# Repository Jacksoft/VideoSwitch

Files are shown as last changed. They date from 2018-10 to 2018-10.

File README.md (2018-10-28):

# VideoSwitch
VideoSwitch sources (PIC + Schematic)
This project is a VideoSwitch for retro devices (that uses SCART/Composite) and is based on a mainboard composed by a PIC microcontroller, a main switch/selector and eight multiplexer, and a daughterboard (to be designed) to add eight more ports (up to two for a total of 24 inputs, not guaranteed until I'll produce a prototype for the right tests).
On the mainboard can be connected an 8x2 LCD character display (or biggher by modifying the firmware), two buttons for the input port selection and an IR receiver (not implemented yet firmware side, need to write the NEC IR library).
The firmware is in MikroBASIC (yes, I'm lazy and this language isn't the best for microcontrollers, I know).
Find out more on http://blog.jacksoftlabs.com/digital-video-switch-for-retro-devices/

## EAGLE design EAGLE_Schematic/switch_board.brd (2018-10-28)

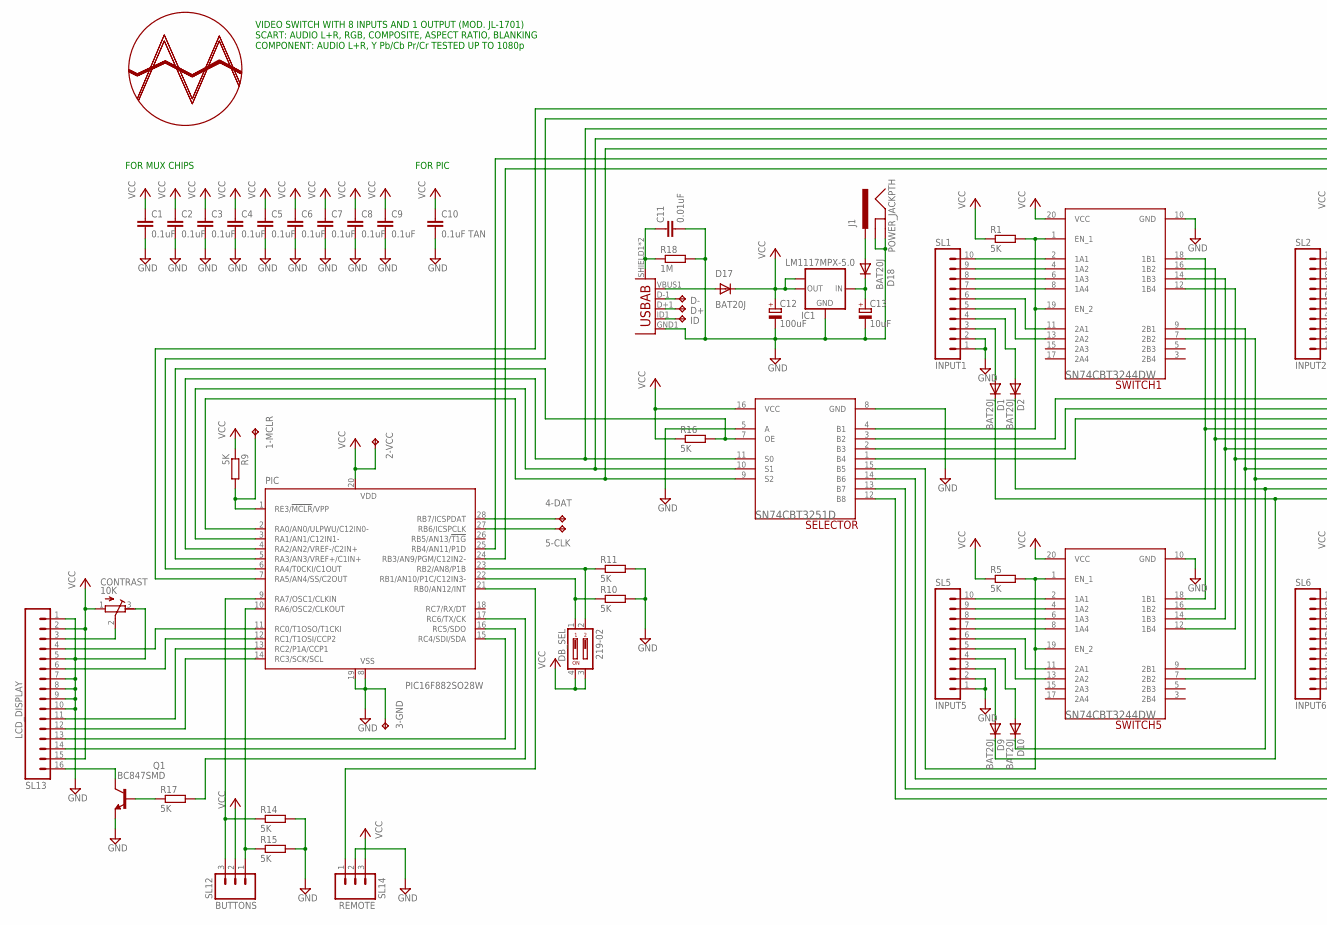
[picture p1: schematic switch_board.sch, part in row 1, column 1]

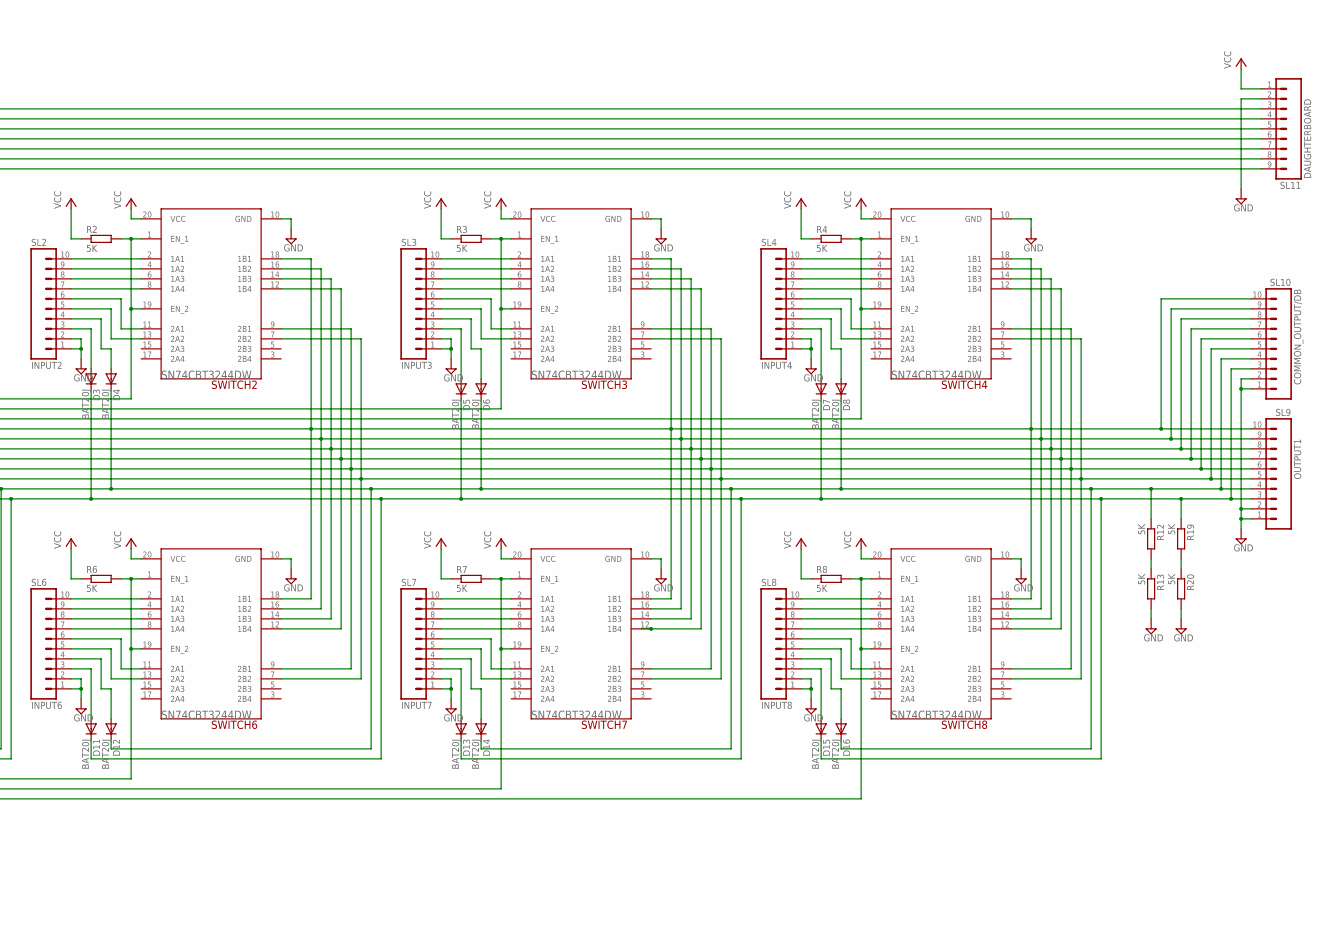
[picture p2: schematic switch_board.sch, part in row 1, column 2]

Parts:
1-MCLR, 2-VCC, 3-GND, 4-DAT, 5-CLK: TPB1,27; B1,27
C1, C2, C3, C4, C5, C6, C7, C8, C9: 0.1uF; C0603
C10: 0.1uF TAN; C3216
C11: 0.01uF; C0603
C12: 100uF; 153CLV-0405
C13: 10uF; 153CLV-0405
CONTRAST: 10K; RTRIM3304W
D1, D2, D3, D4, D5, D6, D7, D8, D9, D10, D11, D12, D13, D14, D15, D16, D17, D18: BAT20J; SOD323-W
D+: TPTP06R; TP06R
D-: TPTP06R; TP06R
DB_SEL: 219-02; CTS-219-02
IC1: LM1117MPX-5.0; SOT223
ID: TPTP06R; TP06R
J1: POWER_JACKPTH; POWER_JACK_PTH
PIC: PIC16F882SO28W; 16F882
Q1: BC847SMD; SOT23
R1, R2, R3, R4, R5, R6, R7, R8, R9, R10, R11, R12, R13, R14, R15, R16, R17, R19, R20: 5K; R0603
R18: 1M; R0603
SELECTOR: SN74CBT3251D; SOIC127P1032X265-16N
SL1: INPUT1; 10P
SL2: INPUT2; 10P
SL3: INPUT3; 10P
SL4: INPUT4; 10P
SL5: INPUT5; 10P
SL6: INPUT6; 10P
SL7: INPUT7; 10P
SL8: INPUT8; 10P
SL9: OUTPUT1; 10P
SL10: COMMON_OUTPUT/DB; 10P
SL11: DAUGHTERBOARD; 09P
SL12: BUTTONS; 03P
SL13: LCD_DISPLAY; 16P
SL14: REMOTE; 03P
SWITCH1, SWITCH2, SWITCH3, SWITCH4, SWITCH5, SWITCH6, SWITCH7, SWITCH8: SN74CBT3244DW; SOIC127P1032X265-20N
U$1: JACKSOFTLABS-LOGOLONGTEXT; LOGO-LONGTEXT
USB: USB_POWER; USB-MICRO-SMD

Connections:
GND: 3-GND.TP, C1.2, C2.2, C3.2, C4.2, C5.2, C6.2, C7.2, C8.2, C9.2, C10.2, C11.2, C12.-, C13.-, CONTRAST.3 (E), IC1.1 (GND), J1.GND, J1.GNDBREAK, PIC.8 (VSS), PIC.19 (VSS), Q1.2 (E), R10.2, R11.2, R13.2, R14.2, R15.2, R18.2, R20.2, SELECTOR.5 (A), SELECTOR.8 (GND), SL1.1, SL1.2, SL2.1, SL2.2, SL3.1, SL3.2, SL4.1, SL4.2, SL5.1, SL5.2, SL6.1, SL6.2, SL7.1, SL7.2, SL8.1, SL8.2, SL9.1, SL9.2, SL10.1, SL10.2, SL11.2, SL13.1, SL13.5, SL13.7, SL13.8, SL13.9, SL13.10, SL14.2, SWITCH1.10 (GND), SWITCH2.10 (GND), SWITCH3.10 (GND), SWITCH4.10 (GND), SWITCH5.10 (GND), SWITCH6.10 (GND), SWITCH7.10 (GND), SWITCH8.10 (GND), USB.GND1 (GND)
unnamed: SL1.10, SWITCH1.2 (1A1)
unnamed: SL1.9, SWITCH1.4 (1A2)
unnamed: SL1.8, SWITCH1.6 (1A3)
unnamed: SL1.7, SWITCH1.8 (1A4)
unnamed: SL1.6, SWITCH1.11 (2A1)
unnamed: SL1.5, SWITCH1.13 (2A2)
unnamed: D2.A, SL1.4
unnamed: D1.A, SL1.3
unnamed: R1.2, SELECTOR.4 (B1), SWITCH1.1 (EN_1), SWITCH1.19 (EN_2)
unnamed: SL2.10, SWITCH2.2 (1A1)
unnamed: SL2.9, SWITCH2.4 (1A2)
unnamed: SL2.8, SWITCH2.6 (1A3)
unnamed: SL2.7, SWITCH2.8 (1A4)
unnamed: SL2.6, SWITCH2.11 (2A1)
unnamed: SL2.5, SWITCH2.13 (2A2)
unnamed: D4.A, SL2.4
unnamed: D3.A, SL2.3
unnamed: R2.2, SELECTOR.3 (B2), SWITCH2.1 (EN_1), SWITCH2.19 (EN_2)
unnamed: SL3.10, SWITCH3.2 (1A1)
unnamed: SL3.9, SWITCH3.4 (1A2)
unnamed: SL3.8, SWITCH3.6 (1A3)
unnamed: SL3.7, SWITCH3.8 (1A4)
unnamed: SL3.6, SWITCH3.11 (2A1)
unnamed: SL3.5, SWITCH3.13 (2A2)
unnamed: D6.A, SL3.4
unnamed: D5.A, SL3.3
unnamed: R3.2, SELECTOR.2 (B3), SWITCH3.1 (EN_1), SWITCH3.19 (EN_2)
unnamed: SL4.10, SWITCH4.2 (1A1)
unnamed: SL4.9, SWITCH4.4 (1A2)
unnamed: SL4.8, SWITCH4.6 (1A3)
unnamed: SL4.7, SWITCH4.8 (1A4)
unnamed: SL4.6, SWITCH4.11 (2A1)
unnamed: SL4.5, SWITCH4.13 (2A2)
unnamed: D8.A, SL4.4
unnamed: D7.A, SL4.3
unnamed: R4.2, SELECTOR.1 (B4), SWITCH4.1 (EN_1), SWITCH4.19 (EN_2)
unnamed: SL9.10, SL10.10, SWITCH1.18 (1B1), SWITCH2.18 (1B1), SWITCH3.18 (1B1), SWITCH4.18 (1B1), SWITCH5.18 (1B1), SWITCH6.18 (1B1), SWITCH7.18 (1B1), SWITCH8.18 (1B1)
unnamed: SL9.9, SL10.9, SWITCH1.16 (1B2), SWITCH2.16 (1B2), SWITCH3.16 (1B2), SWITCH4.16 (1B2), SWITCH5.16 (1B2), SWITCH6.16 (1B2), SWITCH7.16 (1B2), SWITCH8.16 (1B2)
unnamed: PIC.11 (RC0/T1OSO/T1CKI), SL13.4
unnamed: PIC.12 (RC1/T1OSI/CCP2), SL13.6
unnamed: PIC.13 (RC2/P1A/CCP1), SL13.11
unnamed: DB_SEL.1, PIC.22 (RB1/AN10/P1C/C12IN3-), R10.1
unnamed: PIC.14 (RC3/SCK/SCL), SL13.12
unnamed: CONTRAST.2 (S), SL13.3
unnamed: SL5.10, SWITCH5.2 (1A1)
unnamed: SL5.9, SWITCH5.4 (1A2)
unnamed: SL5.8, SWITCH5.6 (1A3)
unnamed: SL5.7, SWITCH5.8 (1A4)
unnamed: SL5.6, SWITCH5.11 (2A1)
unnamed: SL5.5, SWITCH5.13 (2A2)
unnamed: D10.A, SL5.4
unnamed: D9.A, SL5.3
unnamed: R5.2, SELECTOR.15 (B5), SWITCH5.1 (EN_1), SWITCH5.19 (EN_2)
unnamed: SL6.10, SWITCH6.2 (1A1)
unnamed: SL6.9, SWITCH6.4 (1A2)
unnamed: SL6.8, SWITCH6.6 (1A3)
unnamed: SL6.7, SWITCH6.8 (1A4)
unnamed: SL6.6, SWITCH6.11 (2A1)
unnamed: SL6.5, SWITCH6.13 (2A2)
unnamed: D12.A, SL6.4
unnamed: D11.A, SL6.3
unnamed: R6.2, SELECTOR.14 (B6), SWITCH6.1 (EN_1), SWITCH6.19 (EN_2)
unnamed: SL7.10, SWITCH7.2 (1A1)
unnamed: SL7.9, SWITCH7.4 (1A2)
unnamed: SL7.8, SWITCH7.6 (1A3)
unnamed: SL7.7, SWITCH7.8 (1A4)
unnamed: SL7.6, SWITCH7.11 (2A1)
unnamed: SL7.5, SWITCH7.13 (2A2)
unnamed: D14.A, SL7.4
unnamed: D13.A, SL7.3
unnamed: R7.2, SELECTOR.13 (B7), SWITCH7.1 (EN_1), SWITCH7.19 (EN_2)
unnamed: SL8.10, SWITCH8.2 (1A1)
unnamed: SL8.9, SWITCH8.4 (1A2)
unnamed: SL8.8, SWITCH8.6 (1A3)
unnamed: SL8.7, SWITCH8.8 (1A4)
unnamed: SL8.6, SWITCH8.11 (2A1)
unnamed: SL8.5, SWITCH8.13 (2A2)
unnamed: D16.A, SL8.4
unnamed: D15.A, SL8.3
unnamed: R8.2, SELECTOR.12 (B8), SWITCH8.1 (EN_1), SWITCH8.19 (EN_2)
unnamed: DB_SEL.2, PIC.23 (RB2/AN8/P1B), R11.1
unnamed: 1-MCLR.TP, PIC.1 (RE3/!MCLR!/VPP), R9.2
unnamed: PIC.5 (RA3/AN3/VREF+/C1IN+), R16.2, SELECTOR.7 (OE)
unnamed: C11.1, R18.1, USB.SHIELD1 (SHIELD), USB.SHIELD2 (SHIELD)
unnamed: PIC.4 (RA2/AN2/VREF-/C2IN+), SELECTOR.11 (S0), SL11.5
unnamed: PIC.3 (RA1/AN1/C12IN1-), SELECTOR.10 (S1), SL11.6
unnamed: PIC.2 (RA0/AN0/ULPWU/C12IN0-), SELECTOR.9 (S2), SL11.7
unnamed: PIC.6 (RA4/T0CKI/C1OUT), SL11.4
unnamed: 4-DAT.TP, PIC.28 (RB7/ICSPDAT)
unnamed: 5-CLK.TP, PIC.27 (RB6/ICSPCLK)
unnamed: PIC.7 (RA5/AN4/SS/C2OUT), SL11.3
unnamed: Q1.3 (C), SL13.16
unnamed: Q1.1 (B), R17.1
unnamed: D17.A, USB.VBUS1 (VBUS)
unnamed: PIC.21 (RB0/AN12/INT), SL14.1
unnamed: PIC.15 (RC4/SDI/SDA), SL13.13
unnamed: PIC.16 (RC5/SDO), SL13.14
unnamed: PIC.17 (RC6/TX/CK), R17.2
unnamed: C13.+, D18.C, IC1.3 (IN)
unnamed: PIC.10 (RA6/OSC2/CLKOUT), R15.1, SL12.1
unnamed: PIC.9 (RA7/OSC1/CLKIN), R14.1, SL12.3
unnamed: D1.C, D3.C, D5.C, D7.C, D9.C, D11.C, D13.C, D15.C, R19.1, SL9.3, SL10.3
unnamed: D2.C, D4.C, D6.C, D8.C, D10.C, D12.C, D14.C, D16.C, R12.1, SL9.4, SL10.4
unnamed: SL9.5, SL10.5, SWITCH1.7 (2B2), SWITCH2.7 (2B2), SWITCH3.7 (2B2), SWITCH4.7 (2B2), SWITCH5.7 (2B2), SWITCH6.7 (2B2), SWITCH7.7 (2B2), SWITCH8.7 (2B2)
unnamed: SL9.6, SL10.6, SWITCH1.9 (2B1), SWITCH2.9 (2B1), SWITCH3.9 (2B1), SWITCH4.9 (2B1), SWITCH5.9 (2B1), SWITCH6.9 (2B1), SWITCH7.9 (2B1), SWITCH8.9 (2B1)
unnamed: SL9.7, SL10.7, SWITCH1.12 (1B4), SWITCH2.12 (1B4), SWITCH3.12 (1B4), SWITCH4.12 (1B4), SWITCH5.12 (1B4), SWITCH6.12 (1B4), SWITCH7.12 (1B4), SWITCH8.12 (1B4)
unnamed: SL9.8, SL10.8, SWITCH1.14 (1B3), SWITCH2.14 (1B3), SWITCH3.14 (1B3), SWITCH4.14 (1B3), SWITCH5.14 (1B3), SWITCH6.14 (1B3), SWITCH7.14 (1B3), SWITCH8.14 (1B3)
unnamed: D18.A, J1.PWR
unnamed: D-.TP, USB.D-1 (D-)
unnamed: D+.TP, USB.D+1 (D+)
unnamed: ID.TP, USB.ID1 (USBID)
unnamed: R12.2, R13.1
unnamed: R19.2, R20.1
unnamed: PIC.25 (RB4/AN11/P1D), SL11.8
unnamed: PIC.24 (RB3/AN9/PGM/C12IN2-), SL11.9
VCC: 2-VCC.TP, C1.1, C2.1, C3.1, C4.1, C5.1, C6.1, C7.1, C8.1, C9.1, C10.1, C12.+, CONTRAST.1 (A), D17.C, DB_SEL.3, DB_SEL.4, IC1.2 (OUT), IC1.TAB (OUT1), PIC.20 (VDD), R1.1, R2.1, R3.1, R4.1, R5.1, R6.1, R7.1, R8.1, R9.1, R16.1, SELECTOR.16 (VCC), SL11.1, SL12.2, SL13.2, SL13.15, SL14.3, SWITCH1.20 (VCC), SWITCH2.20 (VCC), SWITCH3.20 (VCC), SWITCH4.20 (VCC), SWITCH5.20 (VCC), SWITCH6.20 (VCC), SWITCH7.20 (VCC), SWITCH8.20 (VCC)

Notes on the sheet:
FOR MUX CHIPS
FOR PIC
VIDEO SWITCH WITH 8 INPUTS AND 1 OUTPUT (MOD. JL-1701) SCART: AUDIO L+R, RGB, COMPOSITE, ASPECT RATIO, BLANKING COMPONENT: AUDIO L+R, Y Pb/Cb Pr/Cr TESTED UP TO 1080p

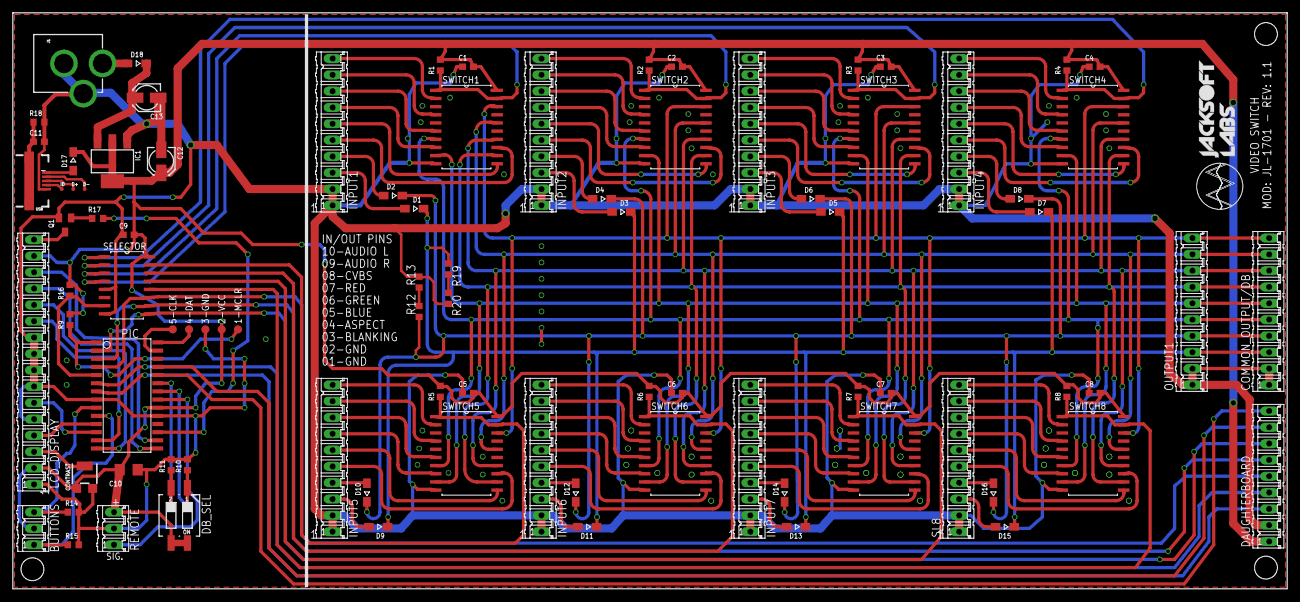
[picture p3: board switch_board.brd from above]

Board: 2 copper layers, 198.4 x 89.7 mm, 90 parts (0 on the bottom side), 117 nets.

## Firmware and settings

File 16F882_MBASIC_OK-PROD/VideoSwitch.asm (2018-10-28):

_DecToBin:

;VideoSwitch.mbas,37 :: 		DIM tmpport AS STRING[3]
	MOVF       R0+0, 0
	MOVWF      DecToBin_local_result+0
;VideoSwitch.mbas,39 :: 		CASE 1
	MOVF       FARG_DecToBin_decin+0, 0
	XORLW      1
	BTFSS      STATUS+0, 2
	GOTO       L__DecToBin4
;VideoSwitch.mbas,40 :: 		tmpport = "000"
	MOVLW      48
	MOVWF      DecToBin_tmpport+0
	MOVLW      48
	MOVWF      DecToBin_tmpport+1
	MOVLW      48
	MOVWF      DecToBin_tmpport+2
	CLRF       DecToBin_tmpport+3
	GOTO       L__DecToBin1
L__DecToBin4:
;VideoSwitch.mbas,41 :: 		CASE 2
	MOVF       FARG_DecToBin_decin+0, 0
	XORLW      2
	BTFSS      STATUS+0, 2
	GOTO       L__DecToBin7
;VideoSwitch.mbas,42 :: 		tmpport = "001"
	MOVLW      48
	MOVWF      DecToBin_tmpport+0
	MOVLW      48
	MOVWF      DecToBin_tmpport+1
	MOVLW      49
	MOVWF      DecToBin_tmpport+2
	CLRF       DecToBin_tmpport+3
	GOTO       L__DecToBin1
L__DecToBin7:
;VideoSwitch.mbas,43 :: 		CASE 3
	MOVF       FARG_DecToBin_decin+0, 0
	XORLW      3
	BTFSS      STATUS+0, 2
	GOTO       L__DecToBin10
;VideoSwitch.mbas,44 :: 		tmpport = "010"
	MOVLW      48
	MOVWF      DecToBin_tmpport+0
	MOVLW      49
	MOVWF      DecToBin_tmpport+1
	MOVLW      48
	MOVWF      DecToBin_tmpport+2
	CLRF       DecToBin_tmpport+3
	GOTO       L__DecToBin1
L__DecToBin10:
;VideoSwitch.mbas,45 :: 		CASE 4
	MOVF       FARG_DecToBin_decin+0, 0
	XORLW      4
	BTFSS      STATUS+0, 2
	GOTO       L__DecToBin13
;VideoSwitch.mbas,46 :: 		tmpport = "011"
	MOVLW      48
	MOVWF      DecToBin_tmpport+0
	MOVLW      49
	MOVWF      DecToBin_tmpport+1
	MOVLW      49
	MOVWF      DecToBin_tmpport+2
	CLRF       DecToBin_tmpport+3
	GOTO       L__DecToBin1
L__DecToBin13:
;VideoSwitch.mbas,47 :: 		CASE 5
	MOVF       FARG_DecToBin_decin+0, 0
	XORLW      5
	BTFSS      STATUS+0, 2
	GOTO       L__DecToBin16
;VideoSwitch.mbas,48 :: 		tmpport = "100"
	MOVLW      49
	MOVWF      DecToBin_tmpport+0
	MOVLW      48
	MOVWF      DecToBin_tmpport+1
	MOVLW      48
	MOVWF      DecToBin_tmpport+2
	CLRF       DecToBin_tmpport+3
	GOTO       L__DecToBin1
L__DecToBin16:
;VideoSwitch.mbas,49 :: 		CASE 6
	MOVF       FARG_DecToBin_decin+0, 0
	XORLW      6
	BTFSS      STATUS+0, 2
	GOTO       L__DecToBin19
;VideoSwitch.mbas,50 :: 		tmpport = "101"
	MOVLW      49
	MOVWF      DecToBin_tmpport+0
	MOVLW      48
	MOVWF      DecToBin_tmpport+1
	MOVLW      49
	MOVWF      DecToBin_tmpport+2
	CLRF       DecToBin_tmpport+3
	GOTO       L__DecToBin1
L__DecToBin19:
;VideoSwitch.mbas,51 :: 		CASE 7
	MOVF       FARG_DecToBin_decin+0, 0
	XORLW      7
	BTFSS      STATUS+0, 2
	GOTO       L__DecToBin22
;VideoSwitch.mbas,52 :: 		tmpport = "110"
	MOVLW      49
	MOVWF      DecToBin_tmpport+0
	MOVLW      49
	MOVWF      DecToBin_tmpport+1
	MOVLW      48
	MOVWF      DecToBin_tmpport+2
	CLRF       DecToBin_tmpport+3
	GOTO       L__DecToBin1
L__DecToBin22:
;VideoSwitch.mbas,53 :: 		CASE 8
	MOVF       FARG_DecToBin_decin+0, 0
	XORLW      8
	BTFSS      STATUS+0, 2
	GOTO       L__DecToBin25
;VideoSwitch.mbas,54 :: 		tmpport = "111"
	MOVLW      49
	MOVWF      DecToBin_tmpport+0
	MOVLW      49
	MOVWF      DecToBin_tmpport+1
	MOVLW      49
	MOVWF      DecToBin_tmpport+2
	CLRF       DecToBin_tmpport+3
	GOTO       L__DecToBin1
L__DecToBin25:
L__DecToBin1:
;VideoSwitch.mbas,56 :: 		result = tmpport
	MOVF       DecToBin_local_result+0, 0
	MOVWF      FSR
	MOVLW      DecToBin_tmpport+0
	MOVWF      R1+0
	CALL       ___CS2S+0
	CLRF       INDF+0
;VideoSwitch.mbas,57 :: 		END SUB
L_end_DecToBin:
	RETURN
; end of _DecToBin

_main:

;VideoSwitch.mbas,59 :: 		MAIN:
;VideoSwitch.mbas,61 :: 		ADCON0 = 0
	CLRF       ADCON0+0
;VideoSwitch.mbas,62 :: 		ADCON1 = 0
	CLRF       ADCON1+0
;VideoSwitch.mbas,63 :: 		ANSEL = 0
	CLRF       ANSEL+0
;VideoSwitch.mbas,64 :: 		ANSELH = 0
	CLRF       ANSELH+0
;VideoSwitch.mbas,65 :: 		CCP1CON = 0
	CLRF       CCP1CON+0
;VideoSwitch.mbas,66 :: 		CCP2CON = 0
	CLRF       CCP2CON+0
;VideoSwitch.mbas,72 :: 		TRISA = 0xC0                   ' 1100 0000
	MOVLW      192
	MOVWF      TRISA+0
;VideoSwitch.mbas,73 :: 		PORTA = 0x38                   ' 0011 1000
	MOVLW      56
	MOVWF      PORTA+0
;VideoSwitch.mbas,74 :: 		TRISB = 0x07                   ' 0000 0111
	MOVLW      7
	MOVWF      TRISB+0
;VideoSwitch.mbas,75 :: 		PORTB = 0x00                   ' 0000 0000
	CLRF       PORTB+0
;VideoSwitch.mbas,76 :: 		TRISC = 0x00                   ' 0000 0000
	CLRF       TRISC+0
;VideoSwitch.mbas,77 :: 		PORTC = 0x7F                   ' 0111 1111
	MOVLW      127
	MOVWF      PORTC+0
;VideoSwitch.mbas,80 :: 		Line1 = "JACKSOFT"
	MOVLW      74
	MOVWF      _Line1+0
	MOVLW      65
	MOVWF      _Line1+1
	MOVLW      67
	MOVWF      _Line1+2
	MOVLW      75
	MOVWF      _Line1+3
	MOVLW      83
	MOVWF      _Line1+4
	MOVLW      79
	MOVWF      _Line1+5
	MOVLW      70
	MOVWF      _Line1+6
	MOVLW      84
	MOVWF      _Line1+7
	CLRF       _Line1+8
;VideoSwitch.mbas,81 :: 		Line2 = "  LABS  "
	MOVLW      32
	MOVWF      _Line2+0
	MOVLW      32
	MOVWF      _Line2+1
	MOVLW      76
	MOVWF      _Line2+2
	MOVLW      65
	MOVWF      _Line2+3
	MOVLW      66
	MOVWF      _Line2+4
	MOVLW      83
	MOVWF      _Line2+5
	MOVLW      32
	MOVWF      _Line2+6
	MOVLW      32
	MOVWF      _Line2+7
	CLRF       _Line2+8
;VideoSwitch.mbas,83 :: 		Lcd_Init()                     ' Initialize LCD (I'm using an 8x2)
	CALL       _Lcd_Init+0
;VideoSwitch.mbas,84 :: 		Lcd_Cmd(_LCD_CLEAR)            ' Clear Screen
	MOVLW      1
	MOVWF      FARG_Lcd_Cmd_out_char+0
	CALL       _Lcd_Cmd+0
;VideoSwitch.mbas,85 :: 		Lcd_Cmd(_LCD_CURSOR_OFF)       ' Cursor Off (_)
	MOVLW      12
	MOVWF      FARG_Lcd_Cmd_out_char+0
	CALL       _Lcd_Cmd+0
;VideoSwitch.mbas,86 :: 		Lcd_Out(1,1,Line1)             ' Send the first row to the display
	MOVLW      1
	MOVWF      FARG_Lcd_Out_row+0
	MOVLW      1
	MOVWF      FARG_Lcd_Out_column+0
	MOVLW      _Line1+0
	MOVWF      FARG_Lcd_Out_text+0
	CALL       _Lcd_Out+0
;VideoSwitch.mbas,87 :: 		Lcd_Out(2,1,Line2)             ' Send the second row to the display
	MOVLW      2
	MOVWF      FARG_Lcd_Out_row+0
	MOVLW      1
	MOVWF      FARG_Lcd_Out_column+0
	MOVLW      _Line2+0
	MOVWF      FARG_Lcd_Out_text+0
	CALL       _Lcd_Out+0
;VideoSwitch.mbas,89 :: 		PORTC.6 = 1                    ' Power-on the backlight
	BSF        PORTC+0, 6
;VideoSwitch.mbas,91 :: 		Delay_ms(50)
	MOVLW      130
	MOVWF      R12+0
	MOVLW      221
	MOVWF      R13+0
L__main27:
	DECFSZ     R13+0, 1
	GOTO       L__main27
	DECFSZ     R12+0, 1
	GOTO       L__main27
	NOP
	NOP
;VideoSwitch.mbas,93 :: 		MaxSwitches = 8
	MOVLW      8
	MOVWF      _MaxSwitches+0
;VideoSwitch.mbas,94 :: 		IF ((PORTB.1 = 1) AND (PORTB.2 = 0)) THEN
	BTFSC      PORTB+0, 1
	GOTO       L__main82
	BCF        114, 0
	GOTO       L__main83
L__main82:
	BSF        114, 0
L__main83:
	BTFSC      PORTB+0, 2
	GOTO       L__main84
	BSF        3, 0
	GOTO       L__main85
L__main84:
	BCF        3, 0
L__main85:
	BTFSS      114, 0
	GOTO       L__main86
	BTFSS      3, 0
	GOTO       L__main86
	BSF        114, 0
	GOTO       L__main87
L__main86:
	BCF        114, 0
L__main87:
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

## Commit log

2018-10-28 Add files via upload
    PIC source code with HEX
    [VideoSwitch.cfg]
2018-10-28 EAGLE Schematic Files
    [switch_board.brd, switch_board.sch]
2018-10-28 Renaming Resources
    [VideoSwitch.cfg]
2018-10-28 PIC FW sourcecode
    PIC FW sourcecode + HEX in MikroBASIC
    [VideoSwitch.cfg]
2018-10-28 Fixed a text
    [switch_board.sch]

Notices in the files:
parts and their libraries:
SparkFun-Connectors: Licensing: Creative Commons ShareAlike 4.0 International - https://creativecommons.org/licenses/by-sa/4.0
